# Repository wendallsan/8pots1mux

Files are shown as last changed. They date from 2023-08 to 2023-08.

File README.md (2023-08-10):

# 8pots1mux
Here's a super-basic PCB designed to use a CD4051 multiplexor IC to send 8 pot values to your microcontroller (or whatever) of choice!  I've been using them in Daisy Seed and Rasperry Pi Pico projects, they're fun!  

  



Required components (plus Tayda or Mouser links, current as of 2023/08/09):  

- 8x [9mm vertical potentiomenters 100k linear taper](https://www.taydaelectronics.com/100k-ohm-linear-taper-potentiometer-round-knurled-plastic-shaft-pcb-9mm.html)-- like the stuff used in Eurorack!  
- 1x [10nF 0805 capacitor  ](https://www.taydaelectronics.com/10nf-50v-smd-ceramic-chip-capacitor.html)  
- 1x [CD4051 SOIC-Narrow-16 IC](https://www.mouser.com/ProductDetail/Texas-Instruments/CD4051BM96?qs=0le1rQK8zxqMHlJa1GNAzQ%3D%3D)    
- 1x 6 pin 2.54mm spaced connector of your choice ([maybe something like this](https://www.taydaelectronics.com/6-pin-2-54mm-single-row-female-pin-header.html)).

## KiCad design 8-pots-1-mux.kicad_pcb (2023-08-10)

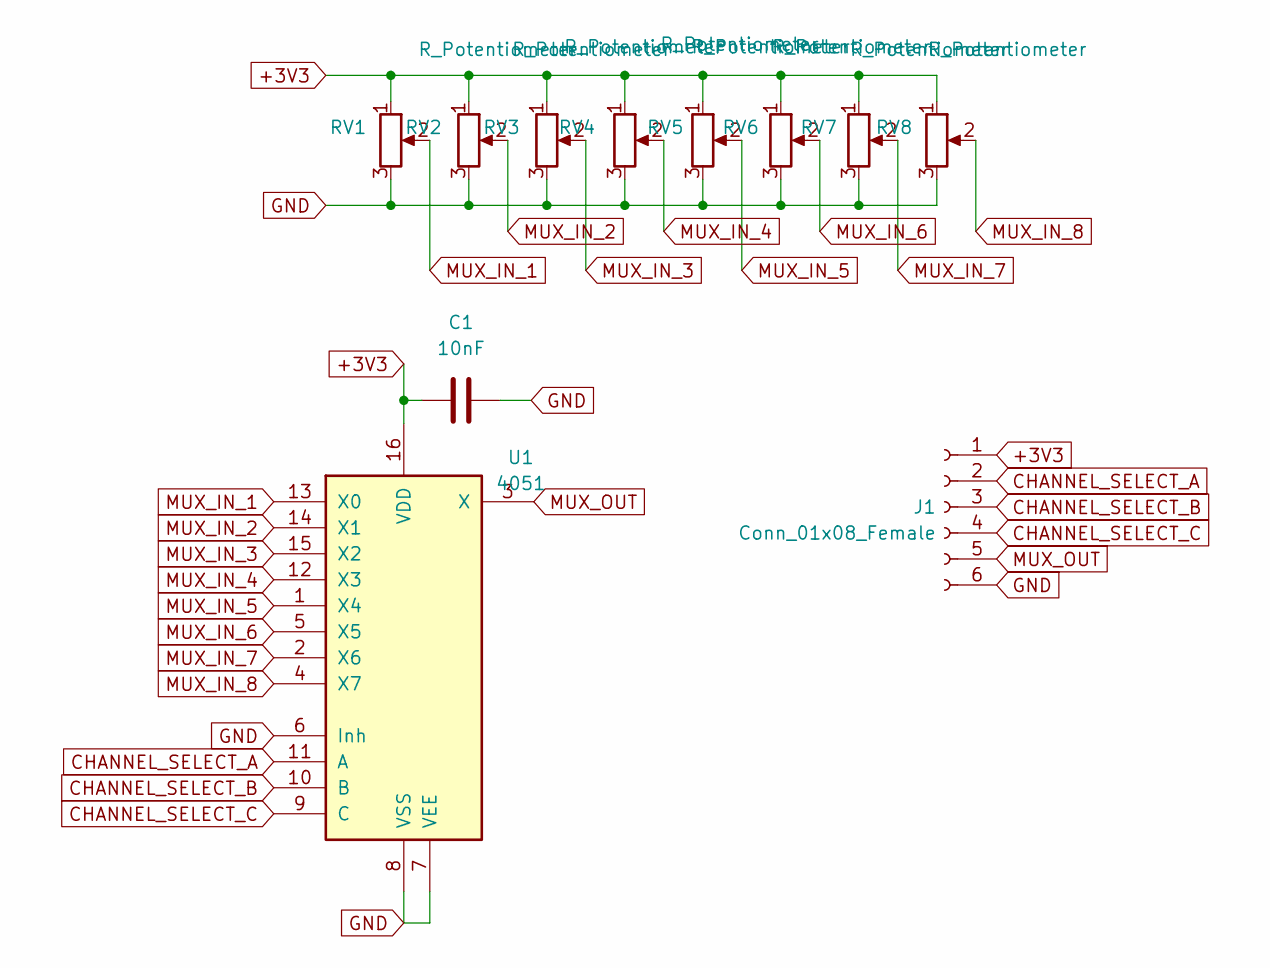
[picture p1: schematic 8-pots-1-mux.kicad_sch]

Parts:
C1: 10nF; C_0805_2012Metric
J1: Conn_01x08_Female; PinSocket_1x06_P2.54mm_Horizontal
RV1, RV2, RV3, RV4, RV5, RV6, RV7, RV8: R_Potentiometer; Potentiometer_Alpha_RD901F-40-00D_Single_Vertical
U1: 4051; SOIC-16_3.9x9.9mm_P1.27mm

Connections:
+3V3: C1.1, J1.1, RV1.1, RV2.1, RV3.1, RV4.1, RV5.1, RV6.1, RV7.1, RV8.1, U1.16 (VDD)
CHANNEL_SELECT_A: J1.2, U1.11 (A)
CHANNEL_SELECT_B: J1.3, U1.10 (B)
CHANNEL_SELECT_C: J1.4, U1.9 (C)
GND: C1.2, J1.6, RV1.3, RV2.3, RV3.3, RV4.3, RV5.3, RV6.3, RV7.3, RV8.3, U1.6 (Inh), U1.7 (VEE), U1.8 (VSS)
MUX_IN_1: RV1.2, U1.13 (X0)
MUX_IN_2: RV2.2, U1.14 (X1)
MUX_IN_3: RV3.2, U1.15 (X2)
MUX_IN_4: RV4.2, U1.12 (X3)
MUX_IN_5: RV5.2, U1.1 (X4)
MUX_IN_6: RV6.2, U1.5 (X5)
MUX_IN_7: RV7.2, U1.2 (X6)
MUX_IN_8: RV8.2, U1.4 (X7)
MUX_OUT: J1.5, U1.3 (X)

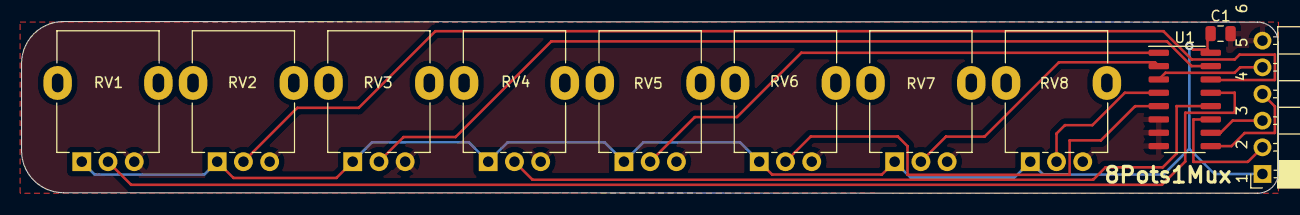
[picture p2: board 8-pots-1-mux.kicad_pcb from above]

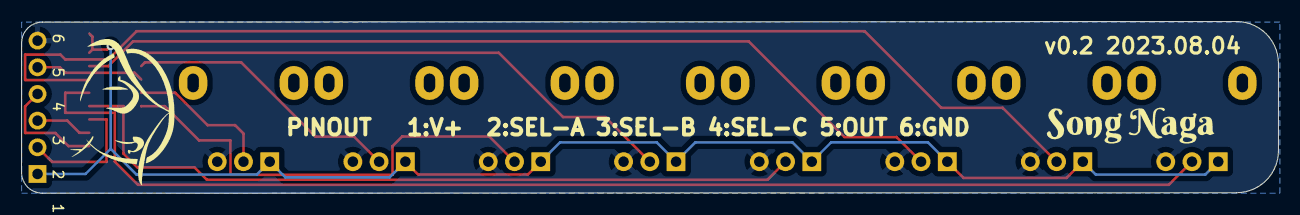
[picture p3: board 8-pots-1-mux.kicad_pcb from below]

Board: 2 copper layers, 119.7 x 16.4 mm, 13 parts (2 on the bottom side), 14 nets.

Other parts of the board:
G1, G2: LOGO
